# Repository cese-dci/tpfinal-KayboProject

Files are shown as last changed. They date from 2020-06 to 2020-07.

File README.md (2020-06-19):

# TP Diseño de Circuitos Impresos [CESE 10Co2019 DCI]
## Autor: Yapura Alberto Emanuel
## Alumno revisor: Del Sancio Leonardo Daniel
### Descripción:

El Acelerómetro consiste en una placa de conexión para el chip ADXL345 de Analog Devices Inc., un acelerómetro de triple eje con interfaces I2C y SPI. Gracias a un regulador y un convertidor de nivel lógico, puede interactuar con microcontroladores de 3V y 5V.

El sensor toma medidas en tres ejes, XY y Z, y puede comunicarse a través de interfaces digitales. I2C y SPI. Puede establecer el nivel de sensibilidad en + -2g, + - 4g, + - 8g o + -16g. El rango más bajo permite una resolución más alta para movimientos lentos, el rango más alto es mejor para rastrear altas velocidades. El chip ADXL345 es uno de los mejores sensores de Analog Devices, conocido por su calidad excepcional como dispositivo MEMS (sistema microelectromecánico). El pin VIN toma hasta 5V de entrada y lo ajusta a 3,3V, disponible

**Características:**
- Sensor Analog Devices ADXL 345
- Alimentación: 3.3 a 5V
- Comunicación: I2C o SPI
- Sensibilidad configurable: +-2g/4g/8g/16g
- Dimensiones: 25x22 mm
- Peso: 1.27 gramos

El proyecto consiste en el diseño utilizando la herramienta Kicat de una **Replica del Acelerómetro adxl345**.

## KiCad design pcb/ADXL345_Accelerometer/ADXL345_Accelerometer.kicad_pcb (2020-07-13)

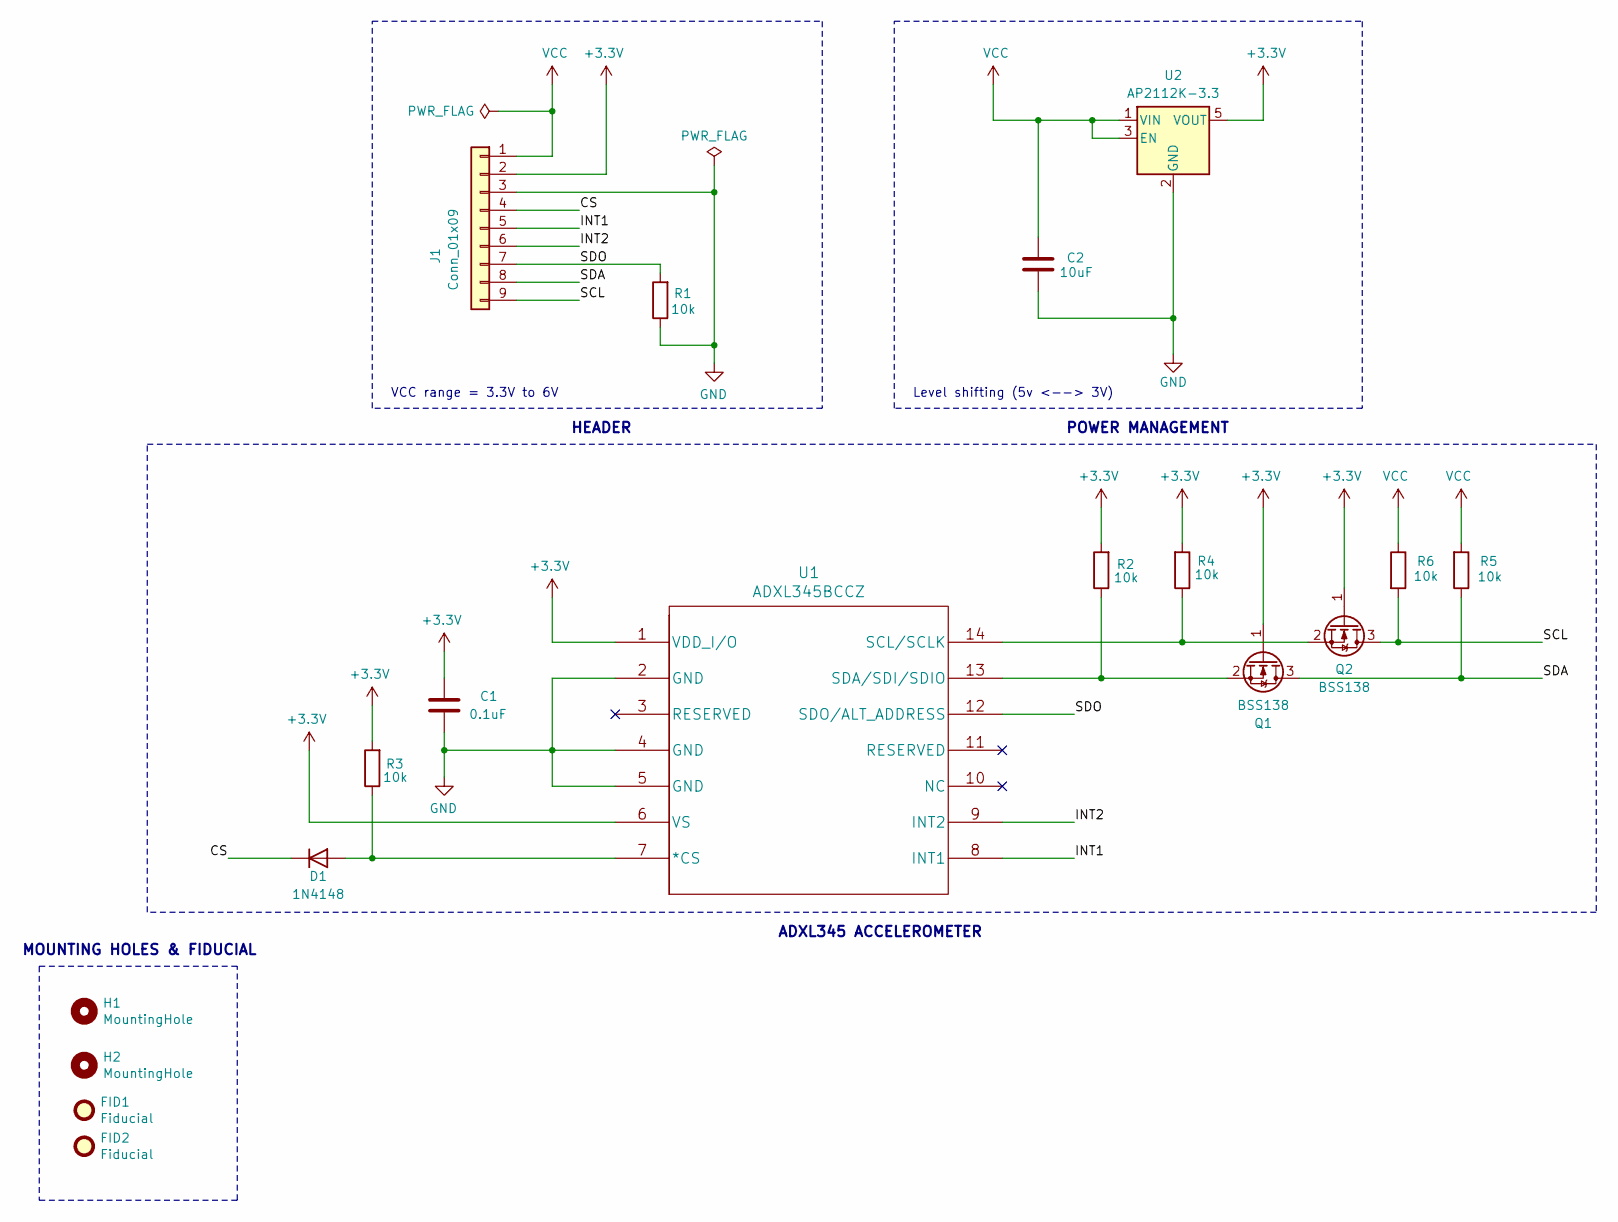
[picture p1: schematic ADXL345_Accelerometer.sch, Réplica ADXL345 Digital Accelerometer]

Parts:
C1: 0.1uF; C_0805_2012Metric
C2: 10uF; C_0805_2012Metric
D1: 1N4148; D_0805_2012Metric
FID1, FID2: Fiducial; Fiducial_0.5mm_Mask1.5mm
H1, H2: MountingHole; MountingHole_2.5mm_Pad
J1: Conn_01x09; PinHeader_1x09_P2.54mm_Vertical; Digi-Key 10129378-909003BLF-ND
Q1, Q2: BSS138; SOT-23; Digi-Key BSS138CT-ND
R1, R2, R3, R4, R5, R6: 10k; D_0805_2012Metric
U1: ADXL345BCCZ; LGA-14_3x5mm_P0.8mm_LayoutBorder1x6y; Digi-Key ADXL345BCCZ-ND
U2: AP2112K-3.3; SOT-23-5; Digi-Key AP2112K-3.3TRG1DITR-ND

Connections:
+3V3: C1.2, J1.2, Q1.1 (G), Q2.1 (G), R2.2, R3.2, R4.2, U1.1 (VDD_I/O), U1.6 (VS), U2.5 (VOUT)
/CS: D1.1 (K), J1.4
/INT1: J1.5, U1.8 (INT1)
/INT2: J1.6, U1.9 (INT2)
/SCL: J1.9, Q2.3 (D), R6.2
/SDA: J1.8, Q1.3 (D), R5.1
/SDO: J1.7, R1.2, U1.12 (SDO/ALT_ADDRESS)
GND: C1.1, C2.2, J1.3, R1.1, U1.2 (GND), U1.4 (GND), U1.5 (GND), U2.2 (GND)
unnamed: D1.2 (A), R3.1, U1.7 (*CS)
unnamed: Q1.2 (S), R2.1, U1.13 (SDA/SDI/SDIO)
unnamed: Q2.2 (S), R4.1, U1.14 (SCL/SCLK)
VCC: C2.1, J1.1, R5.2, R6.1, U2.1 (VIN), U2.3 (EN)

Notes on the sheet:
MOUNTING HOLES & FIDUCIAL
ADXL345 ACCELEROMETER
Level shifting (5v <--> 3V)
VCC range = 3.3V to 6V
POWER MANAGEMENT
HEADER

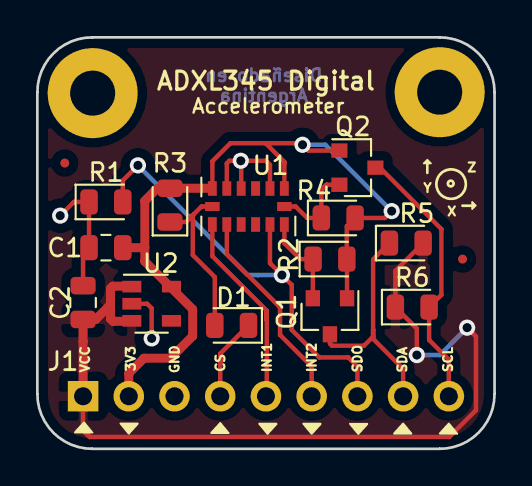
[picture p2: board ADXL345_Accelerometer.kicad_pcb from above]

Board: 2 copper layers, 25.4 x 22.9 mm, 18 parts (1 on the bottom side), 12 nets.

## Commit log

2020-06-08 Primer commit
    Para corregir.
    [ADXL345_Accelerometer.kicad_pcb, ADXL345_Accelerometer.sch]
2020-06-09 Correcciones
    Se corrigieron de acuerdo a las recomendaciones realizadas por el alumno revisor.
    [ADXL345_Accelerometer.kicad_pcb]
2020-06-18 Correcciones
    Se corrigieron segun las recomendaciones realizadas por el docente.
    [ADXL345_Accelerometer.kicad_pcb, ADXL345_Accelerometer.sch]
2020-06-19 Correcciones
    Se corrigieron detalles y se agregaron códigos de catálogo recomendados.
    [ADXL345_Accelerometer.kicad_pcb, ADXL345_Accelerometer.sch]
2020-06-27 Se agregaron fiduciales
    [ADXL345_Accelerometer.kicad_pcb, ADXL345_Accelerometer.sch]
2020-07-02 Correcciones
    Se hicieron las correcciones de acuerdo a las recomendaciones del docente.
    [ADXL345_Accelerometer.kicad_pcb, ADXL345_Accelerometer.sch]
2020-07-02 Modelos 3D del proyecto
    [ADXL345_Accelerometer.kicad_pcb]
2020-07-03 Modelos 3D
    Se generaron los modelos 3D.
    [ADXL345_Accelerometer.kicad_pcb, ADXL345_Accelerometer.sch]
2020-07-10 Correcciones
    Se corrigio de acuerdo a las ultimas recomendaciones realizadas por el docente.
    [ADXL345_Accelerometer.kicad_pcb, ADXL345_Accelerometer.sch]

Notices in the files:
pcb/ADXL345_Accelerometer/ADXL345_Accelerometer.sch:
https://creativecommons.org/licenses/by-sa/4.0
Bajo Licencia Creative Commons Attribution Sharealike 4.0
